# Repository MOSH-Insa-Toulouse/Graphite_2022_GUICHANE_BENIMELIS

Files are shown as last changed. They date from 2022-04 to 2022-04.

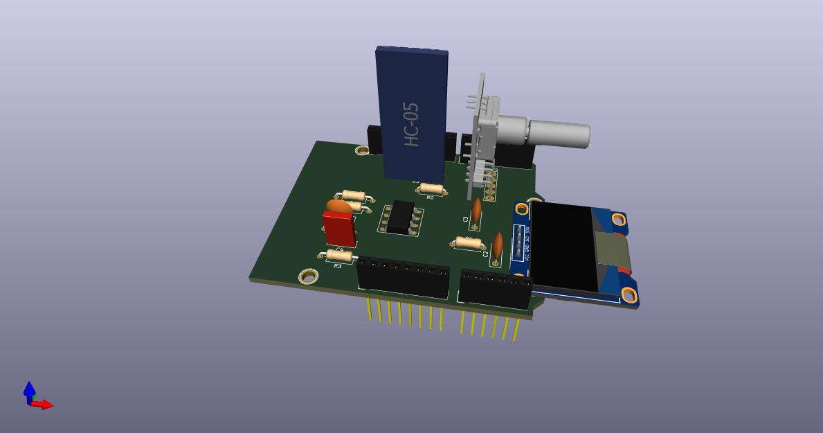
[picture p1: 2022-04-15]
KICAD/PCB_ CARTE ARDUINO VRAIMENT FINALE.jpg

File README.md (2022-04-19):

# Graphite_2022_GUICHANE_BENIMELIS
Projet "Capteur de Graphite", dans le contexte de l'UF **"Du capteur au banc de test"**, département de Génie Physique de l'INSA Toulouse.
***
L'objectif de ce projet est de reprendre les recherches scientifiques sur un capteur low-tech, le **"Pencil Draw Strain Gauges"**. Le fonctionnement de ce capteur est simple. Il suffit de dessiner au crayon à papier sur une feuille et d'appliquer ensuite une contrainte sur celle-ci. La contrainte appliquée va modifier la distance entre les particules de graphique et par conséquent la résistance au passage du courant. Nous avons donc notre capteur. 

<p align="center">
papier graphite
</p>
Nous avons donc décidé de fabriquer nous-même ce capteur et de le tester. Les étapes et le matériel nécessaire à cette réalisation son détaillés ci-dessous. 

## Sommaire
* [1. Livrables](#PremiereSection)
* [2. Matériel nécessaire](#DeuxiemeSection)
* [3. Simulation sous LTspice](#TroisiemeSection)
* [4. Code Arduino](#SeptiemeSection)
* [5. Application Android](#QuatriemeSection)
* [6. KICAD](#CinquiemeSection)
  * [6.1. Les composants](#CinquiemeSection1)
  * [6.2. La schématique](#CinquiemeSection2)
  * [6.3. Le placement des composants](#CinquiemeSection3)
  * [6.4. La visualisation 3D](#CinquiemeSection4)
* [7. Fabrication du PCB designer sur KICAD](#SixiemeSection)
* [8. Banc de test](#HuigtiemeSection)
  * [8.1. Création du banc](#HuigtiemeSection1)
  * [8.2. Tests effectués](#HuigtiemeSection2)
* [9. Datasheet](#NeuviemeSection)
* [Contacts](#DixiemeSection)

## 1. Livrables 
Ce projet sera évalué au sein de l'UF **"Du capteur au banc de test"**. 
Nous sommes donc amenés à rendre tout un ensemble de livrables que voici:
- Un **code Arduino** permettant de mesurer la déformation du capteur et de piloter à minima un module bluetooth, un encodeur rotatoire et un écran OLED
- Une **carte PCB** se connectant au module **Arduino UNO** contenant à minima un amplificateur transimpédance, un module bluetooth, un écran OLED et un encodeur rotatoire
- Une **application Android APK**
- Une **simulation sous LTspice**
- Un **banc de test** 
- La **datasheet** du capteur de déformation

## 2. Matériel nécessaire
Afin de mener à bien ce projet nous avons eu besoin de: 

* 2 résistance 100kΩ
* 2 résistance 1kΩ
* 1 résistance 10kΩ
* 1 capacité 1μF
* 3 capacité 100nF
* 1 amplificateur opérationnel LTC1050
* 1 module Bluetooth HC05
* 1 écran OLED I2C 0.91
* 1 encodeur rotatoire KY_040
* une feuille de papier avec du graphite (crayon à papier) comme ci-dessous

## 3. Simulation Sous LTspice 
Le capteur de graphite que nous voulons créer délivre un signal de courant très faible, d'environ 100 nA. Le microcontroleur ne peut donc pas mesurer directement ce courant. Nous choisissons donc d'utiliser un amplificateur transimpédance pour convertir une variation de courant en variation de tension et l'amplifier, suivi de plusieurs filtres afin que ce faible signal ne soit pas perturbé par le bruit.

Voici le schéma que nous avons réalisé:
<p align="center">

<p/>

Voici les fonctionnalités des différents composants: 
- R5 protège l'amplificateur opérationnel contre les décharges électrostatiques, avec C1 forme un filtre pour les bruits en tension
- C1 avec R1 forment un filtre pour le bruit en courant 
- R2 est interchangeable pour permettre une adaptation du calibre
- C4 avec R3 forment un filtre actif
- C2 avec R6 forment un filtre de sortie 
- C3 filtre le bruit de l'alimentation

Nous avons simulé notre circuit dans les **conditions nominales**. Voici la réponse de notre circuit:
<p align="center">

</p>
Le capteur est fonctionnel et ne sature pas car la hauteur du plateau est à 1V (inférieur à 5V).

La datasheet de l'amplificateur LTC1050C nous indique que sa **tension d'offset** est de l'ordre 5 µV et que le **maximum d’offset de décalage** est de l’ordre se 0,05µV/°C. Ces valeurs nous semblent acceptables car nous mesurons une tension de 10 mV aux bornes de R1. Cette valeur est 2000 fois supérieure à la tension d’offset de l’amplificateur. Nous pouvons donc choisir cet amplificateur sans problème.

De même le **courant d’offset** indiqué dans la datasheet est de 160 pA. Cette valeur semble acceptable devant le courant circulant dans R1 par exemple qui est de l’ordre de 100 nA. Cette valeur est 625 fois supérieure à la tension d’offset qu’on peut donc négliger. 

Nous devons aussi prendre en compte les caractéristiques de la carte Arduino que nous utilisons:
- Résolution: 10-13 bits
- Vref: 1,1V to 5,0V
- Impédence maximale: 1kOhm-10kOhm
- Fréquence d'échantillonage max: 15kHz

Nous utilisons l'Arduinon Uno à sa fréquence max (15kHz). La **limite de repliement** autrement appelée fréquence de Nyquist, est égale à la moitié de la fréquence d'échantillonage choisie, ici 15kHz, soit à 7,5kHz. Sur la simulation ci-dessous, on peut voir qu'à une fréquence de 7,5kHz, on a un gain d'environ 30db. On peut donc déduire que l'attétuation est d'environ 110dB. 
<p align="center">

</p>

Nous avons ensuite calculé les **fréquences de courpure des différents filtres**:
- Filtre d'entrée (R5 associée à C1) 
<p align="center">
simulation_ac_filtre1
</p>
On obtient à -3dB, une fréquence de coupure de 20Hz ce qui fonctionne bien pour l'entrée du capteur. 

- Filtre actif (R3 associée à C4) 
<p align="center">
simulation_ac_filtre2
</p>
On obtient à -3dB, une fréquence de coupure de 2Hz qui permet de couper le bruit induit par le secteur 50Hz.

- Filtre de sortie (R6 associée à C2) 
<p align="center">
simulation_ac_filtre3
</p>
On obtient à -3dB, une fréquence de coupure de 1,5kHz ce qui fonctionne bien pour l'échantillonage de l'ARDUINO.

En faisant varier C1, nous avons pu observer l'infuence de cette capacité sur **l'atténuation globale d'un bruit de courant de 50Hz**. 
- C1= 1u:
<p align="center">

</p>
-C1=100n:
<p align="center">

</p>

## 4. Code Arduino  

L’objectif de ce projet est de mesurer une valeur de résistance. La première étape du code est donc de lire cette valeur. C’est pourquoi nous utilisons la fonction getResistance(int pin) qui permet de lire une valeur analogique sur le pin A0. Cette valeur est ensuite convertie en tension. Nous relions la valeur de la tension de sortie à la résistance en entrée du circuit.

Une fois cette valeur récupérée, il faut l’afficher sur un écran OLED. Nous avons réfléchi à un menu que nous pourrions actualiser à l’aide d’un encodeur rotatoire.

Notre menu est défini par une fonction updateMenu() dans lequel 4 cas sont observés. Le premier correspond à l'affichage de la résistance, le second de la date, le troisième de l’heure et le dernier est un mini jeu que nous détaillerons plus tard. Pour chaque « case » du menu, une action différente est effectuée. 

L’encodeur rotatoire va avoir un rôle à jouer dans la sélection et l’affichage de ces fonctions. En effet, nous lions les pins CLK et SW de l’encodeur à la commande attachInterrupt(pin, fonction(), état). Chaque fois que l’état est déclenché, fonction() est appelée. Chaque fois que l’état du pin CLK passe de 0 à 1, la fonction doEncoder est appelée. Cette fonction incrémente la variable « menu » qui permet de choisir un des cas observés précédemment. De même, chaque fois que l’état de SW change, la fonction Action() est appelée. Cette fonction commande la variable « menuState » aux valeurs 1 et 0. Lorsque « menuState » == 0, la boucle loop() met à jour le menu en appelant updateMenu(). Lorsque « menuState » == 1, la boucle loop() rentre dans un des choix du menu en appelant executeAction(). 

La fonction graphique est un mini-jeu dont le but est d’aller d’un bout à l’autre de l’écran. On redimensionne la valeur de la résistance sur l’écran OLED puis on augmente ou diminue la résistance pour aller plus haut ou plus bas et esquiver les traits bleus sur le chemin. Si nous touchons une ligne, nous avons perdu.

Pour finir, nous ajoutons le module Bluetooth. Par l’intermédiaire de ce module, nous envoyons la valeur de la résistance à l’application créée sur MIT App Inventor.

## 5. Application Android 
Nous avons ensuite cherché à afficher les valeurs de résistance du capteur sur un téléphone mobile Android. Pour cela nous avons crée une application grâce au site MIT App Inventor. 
Notre interface comprend:
- Un bouton de connexion au bluetooth qui devient vert quand la connexion est établie ou rouge quand elle ne l'est pas
- Un menu déroulant qui permet de choisir ce que l'on veut afficher (valeur de la résistance, graphe de la résistance en fonction du temps ou les deux)
- La valeur de la résistance du capteur de graphène
- Un graphe où s'affiche le tracé de la résistance du capteur en fonction du temps
- Un bouton "Reset" qui permet d'effacer le graphe 
- Une information sur les bits contenus dans le buffer

<p align="center">

</p>

## 6. KICAD 
Nous avons modélisé notre shield PCB sur le logiciel KICAD. Pour cela nous avons **designé tous les composants du PCB et créé leur empreinte** (l'aplificateur, l'écran OLED, le module Bluetooth et l'encodeur rotatoire). Nous avons ensuite créé les **connexions** entre tous les composants et avec la carte Arduino sur le logiciel. Enfin nous avons **modélisé la carte PCB** et créé un **modèle 3D** de l'ensemble. 
### 6.1. Les composants 
* L'amplificateur LTC1050



* L'écran OLED



* L'encodeur rotatoire KY_040



* Le module bluetooth HC05



### 6.2. Schématique 
Une fois les composants créés nous les relions entre eux et avec les broches de la carte Arduino. 
<p align="center">

</p>

### 6.3. Placement des composants 
Nous plaçons ensuite les composants sur le shield et traçons les connexions de sorte que les fils ne se croisent pas. 
<p align="center">

 </p>

### 6.4. Visualisation 3D 
Nous avons, enfin, téléchargé les modèles 3D de nos composants afin de visualiser notre PCB en 3D. Cela nous permet aussi d'effectuer une dernière vérification et de voir qu'aucuns composants ne se chevauchent. 
<p align="center">

<p/>

## 7. Fabrication du shield 

Avec l'aide de Catherine Crouzet, nous avons réalisé le PCB à partir d'une plaquette d'époxy recouverte d'une fine couche de cuivre.
Premièrement nous avons imprimé la modélisation du PCB que nous avions faite sur le logiciel KICAD. Cela joue le rôle de masque lors de l'insolation de la plaquette sous UVs. A l'aide d'unrévélateur nous retirons la partie de la résine qui n'a pas été insolée. Ensuite, la plaquette est placée dans un bain de perchlorure de fer pour la gravure. Le cuivre non protégé par la résine s'enlève et nous obtenons le PCB tel que nous l'avions designé sur KICAD. 
Pour éliminer les dernières traces de résine, on lave le PCB à l'acétone. 
<p align="center">
 
<p/>

Nous avons ensuite percé notre PCB afin d'y insérer les différents composants. Le diamètre des trous varie selon les composants à placer :
* ⌀ 0.8mm : pour l'Amplificateur LTC1050, les résistances et les capacités
* ⌀ 1.0mm : Pour les broches de connexion de la carte Arduino Uno et les différents modules (OLED, bluetooth, encodeur rotatoire)

## 8. Banc de test  
### 8.1. Banc de test  
Nous avons imaginé un banc de test afin de pouvoir tester notre capteur. Nous utilisons un rail sur lequel nous rajoutons deux supports. Entre ces-derniers nous mettrons notre capteur sur une réglette flexible. En faisant varier la distance entre les deux supports, la réglette flexible se courbe. Nous relevons cette courbure et la résistance du capteur associée.
Nous avons imprimé deux pièces 3D afin de réaliser ce banc de test. Ce sont des supports pour la réglette flexible. La partie arrière est légèrement inclinée afin que la réglette ne parte pas lors de la flexion.  
<p align="center">


</p>

### 8.2. Résultats obtenus  
Nous avons fait plusieurs mesures en flexion, en donnant à notre capteur une forme concave puis convexe. Nous utilisons un crayon a papier de type critérium avec une mine HB.
<p align="center">


</p>
On remarque que la résistance diminue lorsqu'on donne une forme convexe à notre capteur et inversement pour le cas concave. Cela est dû au rapprochement ou à l'éloignement des molécules de graphite comme nous l'expliquions plus au plus haut. 

## 9. Datasheet  
A l'aide de nos résultats obtenus lors de nos essais avec le banc de test, nous avons pu mettre au point une datasheet de notre capteur. Celle-ci se trouve dans les fichiers à télécharger. 

## Contacts  
Pour toutes questions n'hésitez pas à nous contacter !
* Marie Bénimélis : benimeli@insa-toulouse.fr
* Mathys Guichané : guichane@insa-toulouse.fr

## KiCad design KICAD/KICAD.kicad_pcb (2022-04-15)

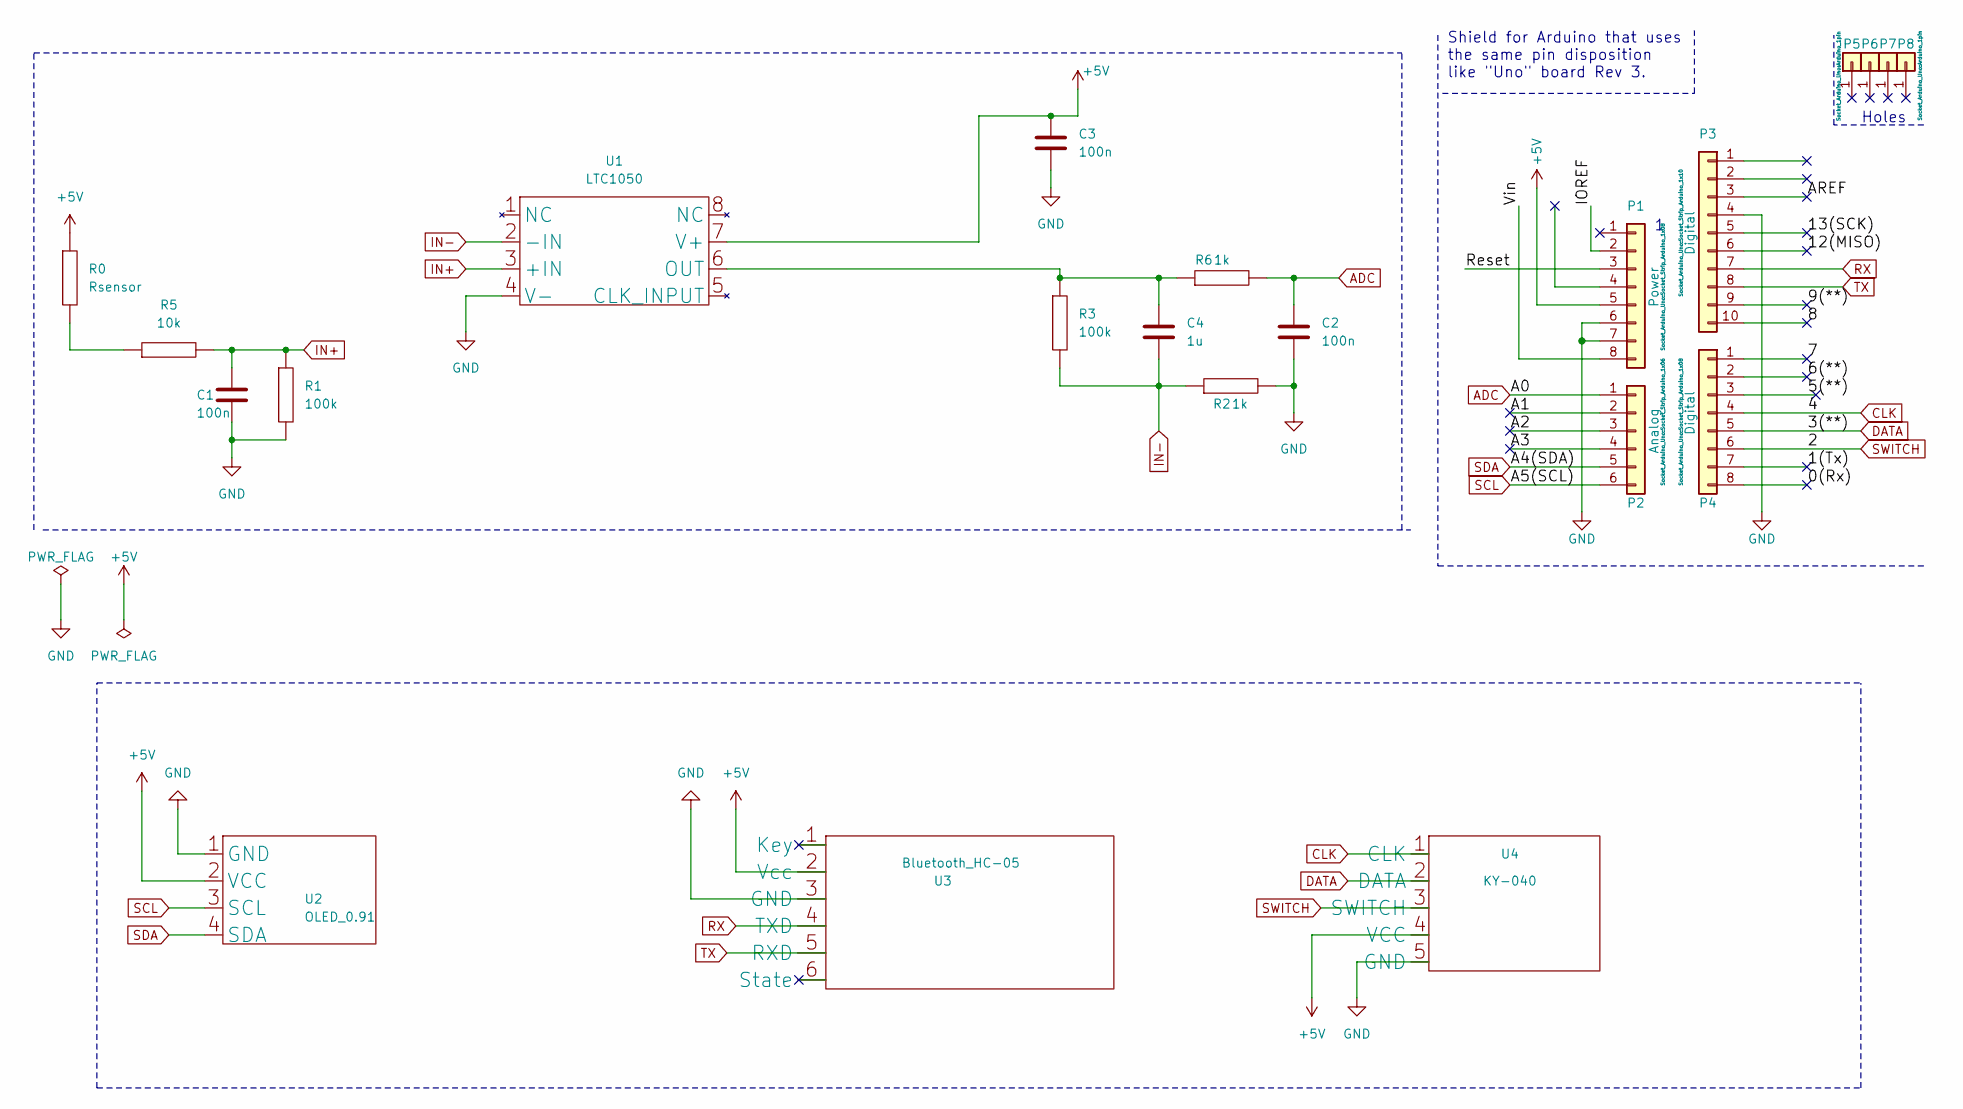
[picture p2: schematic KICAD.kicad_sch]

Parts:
C1, C2, C3: 100n; C_Disc_D7.0mm_W2.5mm_P5.00mm
C4: 1u; C_Rect_L7.0mm_W2.0mm_P5.00mm
P1: Power; Socket_Strip_Arduino_1x08
P2: Analog; Socket_Strip_Arduino_1x06
P3: Digital; Socket_Strip_Arduino_1x10
P4: Digital; Socket_Strip_Arduino_1x08
P5, P6, P7, P8: CONN_01X01; Arduino_1pin
R0: Rsensor; R_Axial_DIN0207_L6.3mm_D2.5mm_P7.62mm_Horizontal
R1, R3: 100k; R_Axial_DIN0207_L6.3mm_D2.5mm_P10.16mm_Horizontal
R2, R6: 1k; R_Axial_DIN0207_L6.3mm_D2.5mm_P7.62mm_Horizontal
R5: 10k; R_Axial_DIN0207_L6.3mm_D2.5mm_P10.16mm_Horizontal
U1: LTC1050; DIP-8_296_ELL
U2: OLED_0.91; SIP-4
U3: Bluetooth_HC-05; SIP-6
U4: KY-040; SIP-5

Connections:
+5V: C3.1, P1.5, R0.1, U1.7 (V+), U2.2 (VCC), U3.2 (Vcc), U4.4 (VCC)
/0(Rx): P4.8
/1(Tx): P4.7
/5(**): P4.3
/6(**): P4.2
/7: P4.1
/8: P3.10
/9(**): P3.9
/12(MISO): P3.6
/13(SCK): P3.5
/A1: P2.2
/A2: P2.3
/A3: P2.4
/AREF: P3.3
/IOREF: P1.2
/Reset: P1.3
/Vin: P1.8
ADC: C2.1, P2.1, R6.2
CLK: P4.4, U4.1 (CLK)
DATA: P4.5, U4.2 (DATA)
GND: C1.2, C2.2, C3.2, P1.6, P1.7, P3.4, R1.2, R2.2, U1.4 (V-), U2.1 (GND), U3.3 (GND), U4.5 (GND)
IN+: C1.1, R1.1, R5.2, U1.3 (+IN)
IN-: C4.2, R2.1, R3.2, U1.2 (-IN)
unnamed: C4.1, R3.1, R6.1, U1.6 (OUT)
unnamed: R0.2, R5.1
RX: P3.7, U3.4 (TXD)
SCL: P2.6, U2.3 (SCL)
SDA: P2.5, U2.4 (SDA)
SWITCH: P4.6, U4.3 (SWITCH)
TX: P3.8, U3.5 (RXD)

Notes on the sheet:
Holes
Shield for Arduino that uses the same pin disposition like "Uno" board Rev 3.

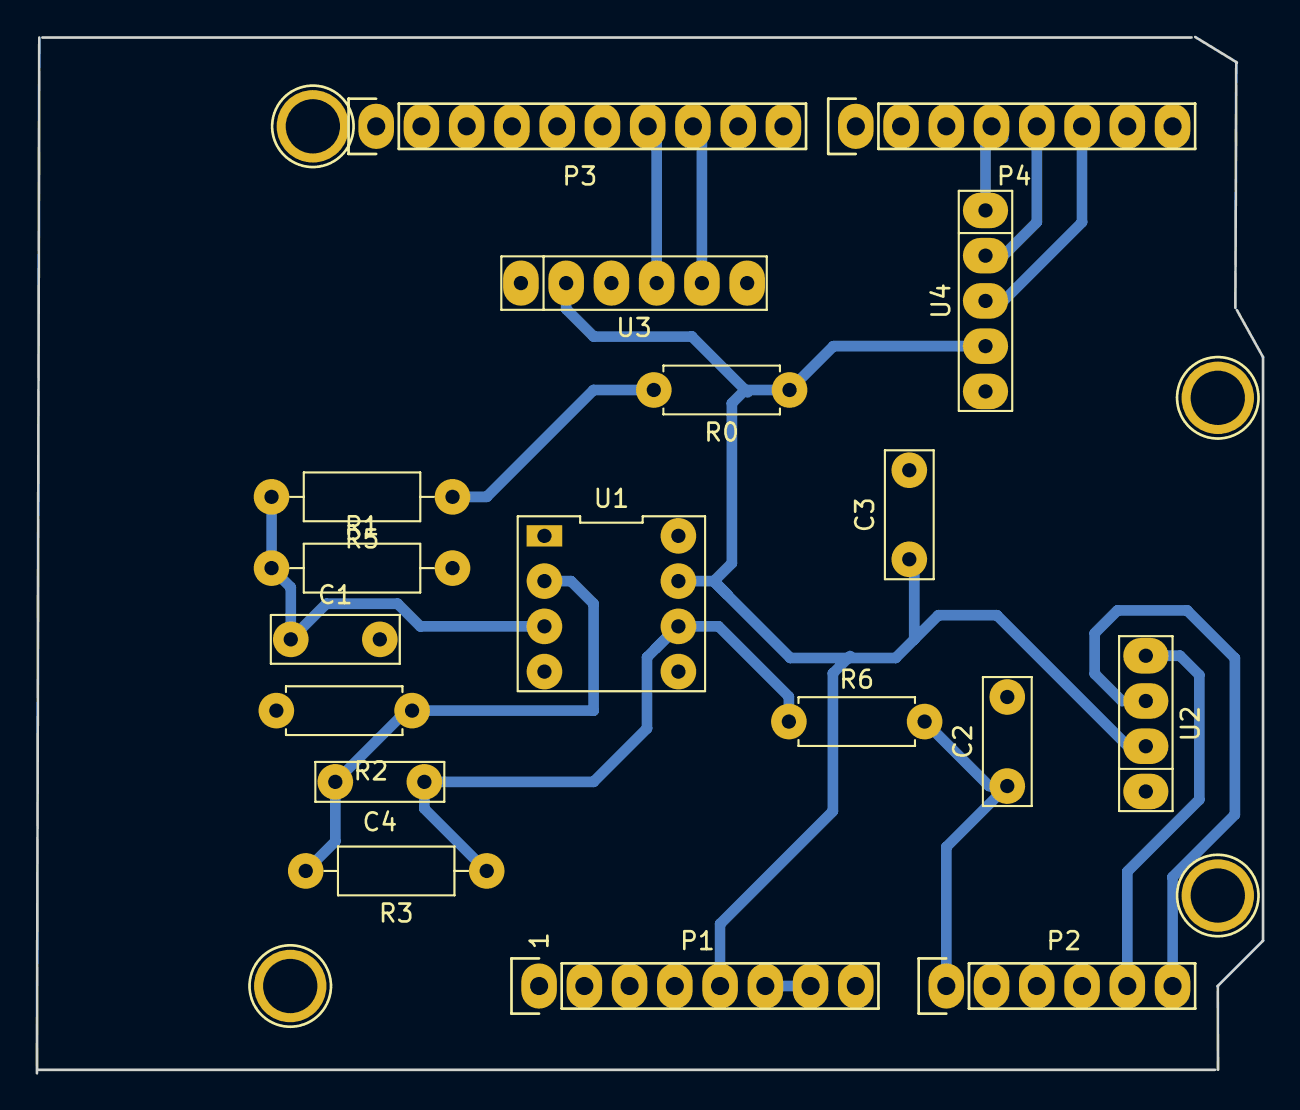
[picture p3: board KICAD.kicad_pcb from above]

Board: 2 copper layers, 68.8 x 58.2 mm, 22 parts (0 on the bottom side), 14 nets.

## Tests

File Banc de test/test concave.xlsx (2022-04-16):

Tests capteur graphite - Flexion concave
Test 1 |  |  |  | Test 2
Rayon du cercle (mm) | Rayon de courbure (mm-1) | Résistance du capteur (R) (Mohm) | R/R0 | Rayon du cercle (mm) | Rayon de courbure (mm-1) | Résistance du capteur (R) (Mohm) | R/R0
73 | 0.01369863014 | 45 | 1 | 72 | 0.01388888889 | 42 | 1
70 | 0.01428571429 | 54.6 | 1.213333333 | 70 | 0.01428571429 | 52.5 | 1.25
65 | 0.01538461538 | 56 | 1.244444444 | 67 | 0.01492537313 | 56 | 1.333333333
61 | 0.01639344262 | 60.7 | 1.348888889 | 59 | 0.01694915254 | 60 | 1.428571429
53 | 0.01886792453 | 62.3 | 1.384444444 | 48 | 0.02083333333 | 65 | 1.547619048
48 | 0.02083333333 | 66 | 1.466666667 | 44 | 0.02272727273 | 66 | 1.571428571
42 | 0.02380952381 | 71 | 1.577777778 | 42 | 0.02380952381 | 70 | 1.666666667
37 | 0.02702702703 | 75 | 1.666666667 | 35 | 0.02857142857 | 77 | 1.833333333
34 | 0.02941176471 | 80 | 1.777777778 | 32 | 0.03125 | 80 | 1.904761905
31 | 0.03225806452 | 83.6 | 1.857777778 | 31 | 0.03225806452 | 85 | 2.023809524
 |  |  |  | Test 2
 |  |  |  | Rayon du cercle (mm) | Rayon de courbure (mm-1) | Résistance du capteur (R) (Mohm) | R/R0
 |  |  |  | 73 | 0.01369863014 | 40 | 1
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

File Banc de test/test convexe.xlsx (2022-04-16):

Tests capteur graphite - Flexion convexe
Test 1 |  |  |  | Test 2
Rayon du cercle (mm) | Rayon de courbure (mm-1) | Résistance du capteur (R) (Mohm) | R/R0 | Rayon du cercle (mm) | Rayon de courbure (mm-1) | Résistance du capteur (R) (Mohm) | R/R0
72 | 0.01388888889 | 33 | 1 | 72 | 0.01388888889 | 42 | 1
68 | 0.01470588235 | 30 | 0.9090909091 | 67 | 0.01492537313 | 38 | 0.9047619048
64 | 0.015625 | 28 | 0.8484848485 | 64 | 0.015625 | 34 | 0.8095238095
61 | 0.01639344262 | 27 | 0.8181818182 | 58 | 0.01724137931 | 31 | 0.7380952381
57 | 0.01754385965 | 26 | 0.7878787879 | 46 | 0.02173913043 | 28.6 | 0.680952381
55 | 0.01818181818 | 25 | 0.7575757576 | 42 | 0.02380952381 | 25 | 0.5952380952
47 | 0.02127659574 | 22 | 0.6666666667 | 39 | 0.02564102564 | 23 | 0.5476190476
44 | 0.02272727273 | 20.4 | 0.6181818182 | 35 | 0.02857142857 | 19.5 | 0.4642857143
40 | 0.025 | 18 | 0.5454545455 | 32 | 0.03125 | 16 | 0.380952381
32 | 0.03125 | 16.5 | 0.5 | 31 | 0.03225806452 | 15 | 0.3571428571
 |  |  |  | Test 3
 |  |  |  | Rayon du cercle (mm) | Rayon de courbure (mm-1) | Résistance du capteur (R) (Mohm) | R/R0
 |  |  |  | 73 | 0.01369863014 | 40 | 1
 |  |  |  | 68 | 0.01470588235 | 36 | 0.9
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

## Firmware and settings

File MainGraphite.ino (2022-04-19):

#include <Adafruit_SSD1306.h>
#include <Adafruit_GFX.h>

int ResistancePin = A0; //the analog pin the TMP36's Vout (sense) pin is connected to
                        //the resolution is 10 mV / degree centigrade
                        //(500 mV offset) to make negative temperatures an option

float R5 = 10000.0;
float R1 = 100000.0;
float Rcal = 1000.0;
float R3 = 100000.0;
float R6 = 1000.0;
float Vcc = 5.0;

#include <Adafruit_SSD1306.h>

#define nombreDePixelsEnLargeur 128         // Taille de l'écran OLED, en pixel, au niveau de sa largeur
#define nombreDePixelsEnHauteur 64          // Taille de l'écran OLED, en pixel, au niveau de sa hauteur
#define brocheResetOLED         -1          // Reset de l'OLED partagé avec l'Arduino (d'où la valeur à -1, et non un numéro de pin)
#define adresseI2CecranOLED     0x3C        // Adresse de "mon" écran OLED sur le bus i2c (généralement égal à 0x3C ou 0x3D)

Adafruit_SSD1306 ecranOLED(nombreDePixelsEnLargeur, nombreDePixelsEnHauteur, &Wire, brocheResetOLED);

/////////Encodeur/////////
#define encoder0PinA  3  //CLK 
#define encoder0PinB  4  //DT 
#define sw 2 // Switch 

/////////Bluetooth/////////
#include <SoftwareSerial.h>
#define rxPin 11 //Broche 5 en tant que RX, � raccorder sur TX du HC-05
#define txPin 10 //Broche 6 en tant que RX, � raccorder sur TX du HC-05
#define baudrate 9600
SoftwareSerial mySerial(rxPin ,txPin);

/////////Variables/////////
int menu = 1; //Variable permettant de choisir le menu
int menuState = 0; //Booléen: Si = 0: update le menu, si = 1: rentre dans la fonction

/////////Variables Debounce/////////
int lastButtonState = LOW; //Stocke la dernière valeur du pin DT
long lastDebounceTime1 = 0; //Première Variable de stockage de temps
long lastDebounceTime2 = 0; //Deuxième variable de stockage de temps


void setup()
{ 
  pinMode(encoder0PinA, INPUT); 
  digitalWrite(encoder0PinA, HIGH);  

  pinMode(encoder0PinB, INPUT); 
  digitalWrite(encoder0PinB, HIGH);      

  pinMode(sw, INPUT_PULLUP);

  attachInterrupt(1, doEncoder, RISING); // Appelle la fonction doEncoder qui incrémente la variable menu
  attachInterrupt(0, Action, CHANGE); //Appelle la fonction Action qui incrémente ou décrémente le booléen menuState

  if(!ecranOLED.begin(SSD1306_SWITCHCAPVCC, adresseI2CecranOLED)) // Arrêt du programme (boucle infinie) si échec d'initialisation 
    while(1);
    ecranOLED.setTextColor(WHITE);
    
  pinMode(rxPin,INPUT); // variable de reception de donnée via RX
  pinMode(txPin,OUTPUT); // variable de transmission de données via TX  
  mySerial.begin(9600);
  
  updateMenu();
  Serial.begin(9600);
  
}

void loop() {
  float resistance = getResistance(ResistancePin); //Récupération de la valeur de résistance provenant du pin A0
  
  if (menuState == 1){      //Condition si le booléen=1: affiche la fonction décrite par la variable menu
    executeAction();
    if (menu == 4){       //Initialise le booléen à 0 lorsqu'on sort de la fonction 4 (Graphique)
      menuState = 0;
    }
  }
  if (menuState == 0){      //Update le menu tant que le booléen est à 0
  updateMenu();
  }
  
  mySerial.write(getResistance(ResistancePin)/1000000);  //Écriture sur le port bluetooth
  Serial.println(getResistance(ResistancePin)/1000000);  //Écriture sur le port série
  while (mySerial.available()){
  Serial.print((char)mySerial.read());  
  }
  delay(1000);
}           

////////// Menu de l'écran OLED ////////////
void updateMenu() {
  switch (menu) {
    
    case 0:
      menu = 1;
      break;
    case 1:
      ecranOLED.clearDisplay();
      ecranOLED.setTextSize(1);
      ecranOLED.setCursor(0, 0);
      ecranOLED.println(">Resistance");
      ecranOLED.setCursor(0, 10);
      ecranOLED.println("Date");
      ecranOLED.setCursor(0, 20);
      ecranOLED.println("Heure");
      ecranOLED.setCursor(0, 30);
      ecranOLED.println("Graphique");
      ecranOLED.display();
      break;
    case 2:
      ecranOLED.clearDisplay();
      ecranOLED.setTextSize(1);
      ecranOLED.setCursor(0, 0);
      ecranOLED.println("Resistance");
      ecranOLED.setCursor(0, 10);
      ecranOLED.println(">Date");
      ecranOLED.setCursor(0, 20);
      ecranOLED.println("Heure");
      ecranOLED.setCursor(0, 30);
      ecranOLED.println("Graphique");
      ecranOLED.display();
      break;
    case 3:
      ecranOLED.clearDisplay();
      ecranOLED.setTextSize(1);
      ecranOLED.setCursor(0, 0);
      ecranOLED.println("Resistance");
      ecranOLED.setCursor(0, 10);
      ecranOLED.println("Date");
      ecranOLED.setCursor(0, 20);
      ecranOLED.println(">Heure");
      ecranOLED.setCursor(0, 30);
      ecranOLED.println("Graphique");
      ecranOLED.display();
      break;
    case 4:
      ecranOLED.clearDisplay();
      ecranOLED.setTextSize(1);
      ecranOLED.setCursor(0, 0);
      ecranOLED.println("Resistance");
      ecranOLED.setCursor(0, 10);
      ecranOLED.println("Date");
      ecranOLED.setCursor(0, 20);
      ecranOLED.println("Heure");
      ecranOLED.setCursor(0, 30);
      ecranOLED.println(">Graphique");
      ecranOLED.display();
      break;      
    case 5:
      menu = 4;
      break;
    
  }
}

////////// Appel des actions à suivre en fonction des cas ////////////
void executeAction() {
  switch (menu) {
    case 1:
      action1();
      break;
    case 2:
      action2();
      break;
    case 3:
      action3();
      break;
    case 4:
      action4();
      break;
  }
}

////////// Actions à suivre en fonction des cas////////////
void action1() {        //Affichage de la résistance en direct
  ecranOLED.clearDisplay();
  ecranOLED.setTextSize(1);
  ecranOLED.setCursor(0, 0);
  ecranOLED.println("Resistance Graphene");
  
  ecranOLED.setTextSize(1);
  float resistance = getResistance(ResistancePin);
  ecranOLED.setCursor(0, 20);
  ecranOLED.println(resistance);
  ecranOLED.setCursor(100, 20);
  ecranOLED.println("Ohm");
  ecranOLED.setCursor(0,50);
  ecranOLED.println(">Quitter");
  ecranOLED.setCursor(64,50);
  ecranOLED.println(">Suivant");
  ecranOLED.display();
  delay(300);

}

void action2() {        //Affichage de la date
  ecranOLED.clearDisplay();
  ecranOLED.setTextSize(2);
  ecranOLED.setTextSize(2);
  ecranOLED.setCursor(0, 0);
  ecranOLED.println("DATE");
  ecranOLED.setTextSize(1);
  ecranOLED.setCursor(0, 20);
  ecranOLED.println("Joyeux anniversaire Cathy!");
  ecranOLED.setCursor(0,50);
  ecranOLED.println(">Quitter");
  ecranOLED.setCursor(64,50);
  ecranOLED.println(">Suivant");
  ecranOLED.display();
  delay(300);
}

void action3() {        //Affichage de l'heure
  ecranOLED.clearDisplay();
  ecranOLED.setTextSize(2);
  ecranOLED.setCursor(0, 0);
  ecranOLED.println("Heure");
  ecranOLED.setTextSize(1);
  ecranOLED.setCursor(0, 20);
  ecranOLED.println("Il est deja deux secondes de plus par rapport au debut du message");
  ecranOLED.setCursor(0,55);
  ecranOLED.println(">Quitter");
  ecranOLED.setCursor(64,55);
  ecranOLED.println(">Suivant");
  ecranOLED.display();
  delay(300);
}

///////////////////Affichage du graphique//////////////////

void action4() {
  ecranOLED.clearDisplay();
  float Rmax = 80000000;  //On définit Rmax et Rminpour pouvoir ramener la valeur de la résistance de 0 à 64 (pixels)
  float Rmin = 10000000;
  int i = 0;
  float resistance;
  
  ecranOLED.drawLine(7,3,7,40,WHITE);  //On dessine les limites du jeu, on doit éviter ces lignes verticales
  ecranOLED.drawLine(15,64,15,49,WHITE);
  ecranOLED.drawLine(30,20,30,40,WHITE);
  ecranOLED.drawLine(47,54,47,34,WHITE);
  ecranOLED.drawLine(64,0,64,64,WHITE);

  
  //unsigned long currentMillis = millis();  //On définit les variables de temps
  unsigned long previousMillis = 0;
  const long interval = 1000;
  int x = 0;
  
  //Tant qu'on a pas appuyé sur l'interrupteur, la boucle continu
  while (millis() != 64){
    //Déclenchement de la condition toutes les 1s
    if (millis() - previousMillis >= interval) {
      resistance = getResistance(ResistancePin);
      previousMillis = millis();
      
      x++;  //Norme de temps sur 1s et non 1000ms
      int resistanceNormee = 64 - (((resistance-Rmin)/(Rmax-Rmin))*64);  //On définit la resistance Normée de 0 à 64 pixels. On rajoute 64 - ... devant pour que le graphique ne soit pas inversé
      
      if (resistanceNormee > 64){
        resistanceNormee = 64;
      }
      if (resistanceNormee < 10){
        resistanceNormee = 10;
      }
      
      Serial.print("Rnorm :");
      Serial.print(resistanceNormee);
      Serial.print("x:");
      Serial.print(x);
      ecranOLED.drawPixel(x, resistanceNormee, WHITE);  //On dessine un pixel toutes les secondes à y=resistanceNormee en fonction de x=t (s) 
      ecranOLED.display();

      //Si le pixel touche la première ligne, on perd
      if ((resistanceNormee >= 3) && (resistanceNormee <= 40) && (x == 7)){
        ecranOLED.clearDisplay();
        ecranOLED.setTextSize(2);
        ecranOLED.setCursor(0, 0);
        ecranOLED.println("PERDU!");
        ecranOLED.setCursor(0,50);
        ecranOLED.println(">Quitter");
        ecranOLED.display();
        delay(5000);
        updateMenu();
        break;
      }

      //Si le pixel touche la troisième ligne, on perd
      if ((resistanceNormee >= 49) && (resistanceNormee <= 64) && (x == 15)){
        ecranOLED.clearDisplay();
        ecranOLED.setTextSize(2);
        ecranOLED.setCursor(0, 0);
        ecranOLED.println("PERDU!");
        ecranOLED.setCursor(0,50);
        ecranOLED.println(">Quitter");
        ecranOLED.display();
        delay(5000);
        updateMenu();
        break;
      }
      
      //Si le pixel touche la quatrième ligne, on perd
      if ((resistanceNormee >= 20) && (resistanceNormee <= 40) && (x == 30)){
        ecranOLED.clearDisplay();
        ecranOLED.setTextSize(2);
        ecranOLED.setCursor(0, 0);
        ecranOLED.println("PERDU!");
        ecranOLED.setCursor(0,50);
        ecranOLED.println(">Quitter");
        ecranOLED.display();
        delay(5000);
        updateMenu();
        break;
      }

      if ((resistanceNormee >= 34) && (resistanceNormee <= 54) && (x == 46)){
        ecranOLED.clearDisplay();
        ecranOLED.setTextSize(2);
        ecranOLED.setCursor(0, 0);
        ecranOLED.println("PERDU!");
        ecranOLED.setCursor(0,50);
        ecranOLED.println(">Quitter");
        ecranOLED.display();
        delay(5000);
        updateMenu();
        break;
      }

      //Si le pixel est arrivé au bout, on gagne
      if(x == 64){
        ecranOLED.clearDisplay();
        ecranOLED.setTextSize(2);
        ecranOLED.setCursor(0, 0);
        ecranOLED.println("GAGNE!");
        ecranOLED.setCursor(0,50);
        ecranOLED.println(">Quitter");
        ecranOLED.display();
        delay(5000);
        updateMenu();
        break;
      }
    }
    delay(300);
    //Si on appuie sur l'interrupteur, on quitte la boucle
    if (digitalRead(sw)==LOW){
    break;
    }
  }
  ecranOLED.clearDisplay();
}

void doEncoder(){
  int reading = digitalRead(encoder0PinB);
  int Temps = millis(); //Temps depuis lequel s'est exécuté le programme
  if (((Temps - lastDebounceTime1) > 200) && (reading != lastButtonState)){  //1er debounce du DT et de la CLK
    lastDebounceTime1 = Temps;  //Stockage de la dernière valeur de temps
    if (reading==HIGH){
      menu++;  //Incrémentation du menu
      if (menu > 4){  //Si on dépasse le nombre de variables dans le menu, on revient à la 1ère variable
        menu = 1;
      }
      lastButtonState = LOW;  //Stockage du dernier état du DT
    } 
  }
}


void Action(){
  int Time = millis(); //Temps depuis lequel s'est exécuté le programme
  if (((Time - lastDebounceTime1) > 500)){  //2ème debounce du SW
    lastDebounceTime1 = Time;
    menuState++;
    if (menuState == 2){  //Si on dépasse 1, on revient à 0: on veut un booléen
      menuState = 0;
    }  
  } 
}                

float getResistance(int pin) {        //Récupération de la valeur de tension sur A0 puis conversion en résistance
  float voltage = analogRead(pin)*0.004882814;  //Conversion * 5(Tension) / 1024(Nombre de bits)
return ((1+(R3/Rcal))*R1*Vcc/voltage-R1-R5);  //Relation entre la tension d'entrée et de sortie 
}
